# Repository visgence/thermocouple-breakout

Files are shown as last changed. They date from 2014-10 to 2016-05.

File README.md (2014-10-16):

The K-Type thermocouple conditioner is an easy way to use a K-Type thermocouple with an Arduino or other microcontrollers. At its heart is a AD595 thermocouple conditioner IC. The AD595 is laser trimmed for accuracy and performs automatic cold-junction compensation, which means you can just drop it into a project and get accurate results right away.

We created the K-Type Thermocouple Conditioner board while rebuilding our reflow toaster oven. The original controller used an AD595 and we were happy with its results. Since the toaster oven is a semi-permanent setup, we gave the board screw terminals and holes for robust mounting.

#### Specs
- [AD595A](http://www.analog.com/static/imported-files/data_sheets/AD594_595.pdf) laser trimmed for K-type thermocouple and 3 degree C basic accuracy
- 10mV / K output, easy to read with any ADC
- K-type input fits standard probes
- Alarm output and LED signals that probe is disconnected
- Screw terminals and mounting holes for easy long-term mounting

#### Use with an Arduino
We built our thermocouple conditioner specifically to use with Arduino and compatible boards. See the [example sketch](https://github.com/visgence/thermocouple-breakout/tree/master/example_code/thermocouple_conditioner_arduino) for a simple example.

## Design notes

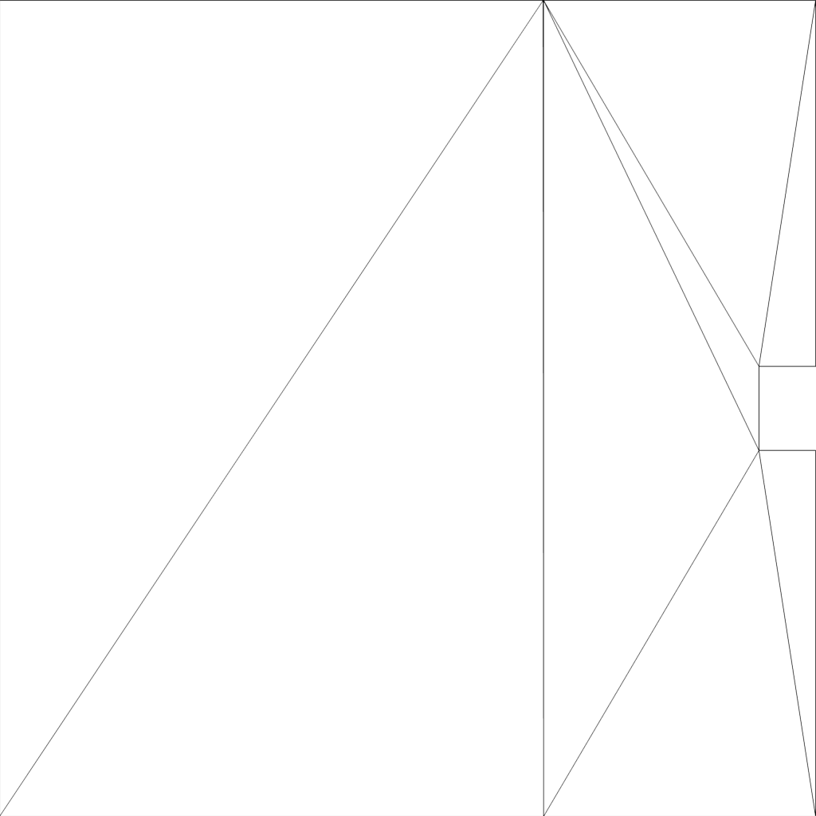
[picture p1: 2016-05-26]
hardware/BlenderModels/ThermoCoupleUVTop.png

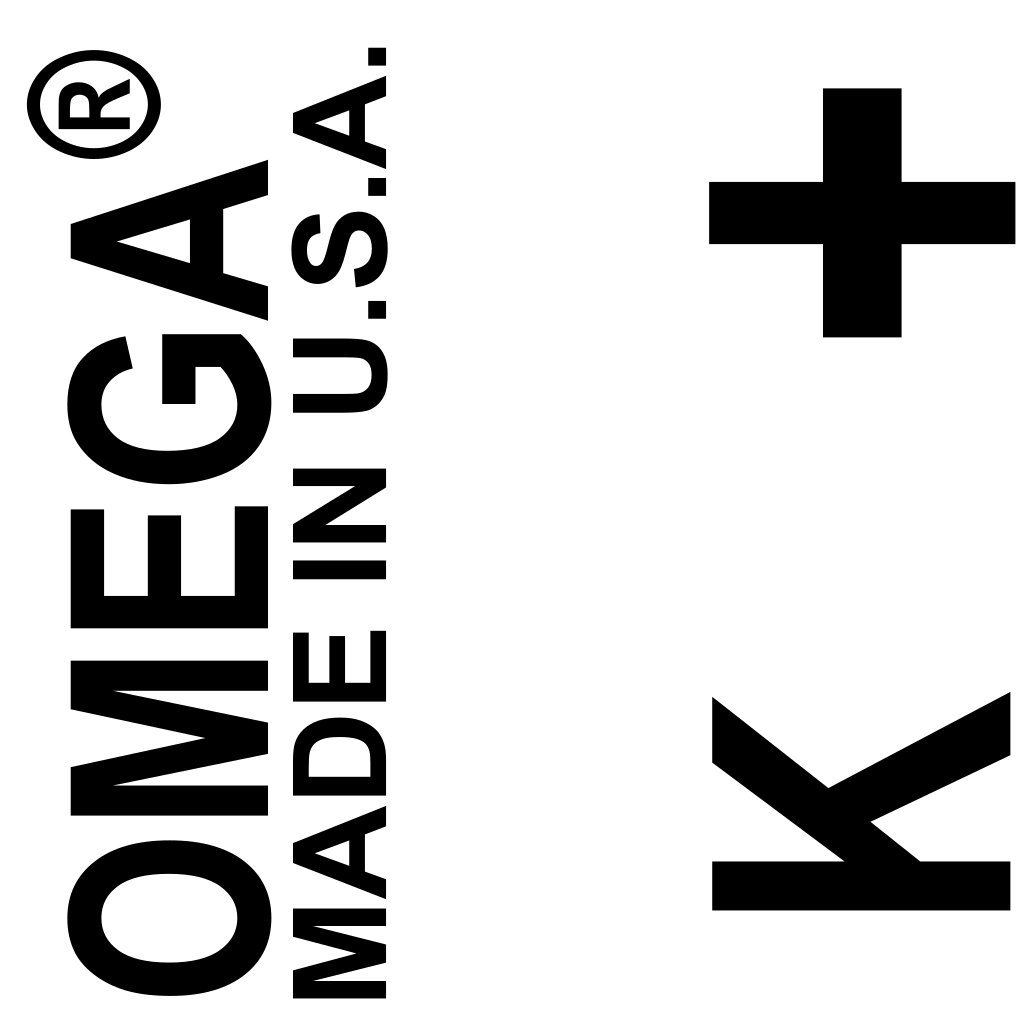
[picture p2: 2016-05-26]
hardware/BlenderModels/ThermoCoupleTopColor.png

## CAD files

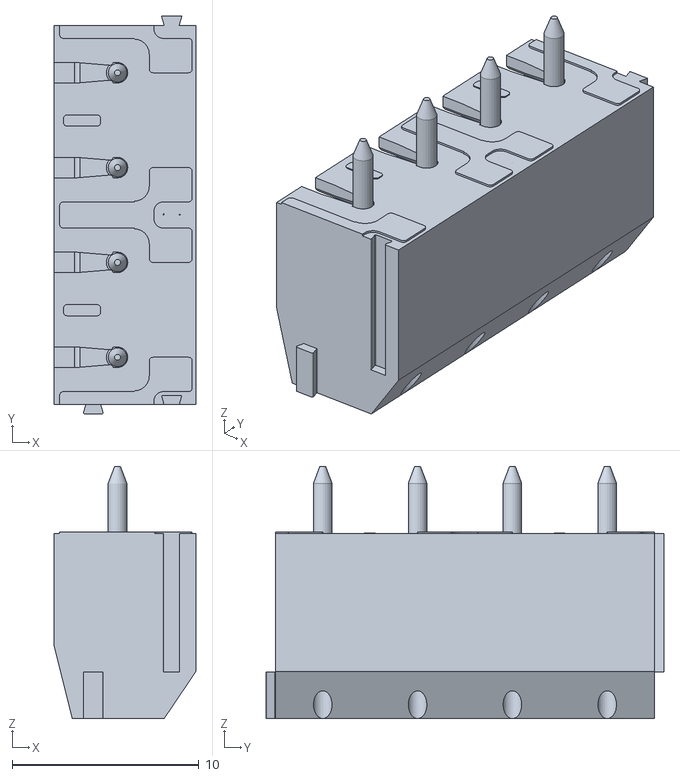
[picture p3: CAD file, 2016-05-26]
hardware/BlenderModels/OSTTCXX2162.obj
7.60 x 21.3 x 13.5

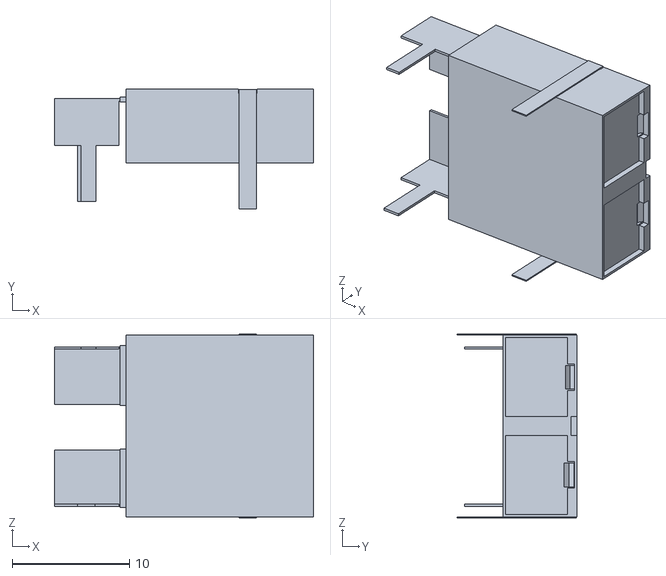
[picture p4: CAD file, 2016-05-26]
hardware/FusionModels/ThermoCouple.stl
22.1 x 10.3 x 15.7

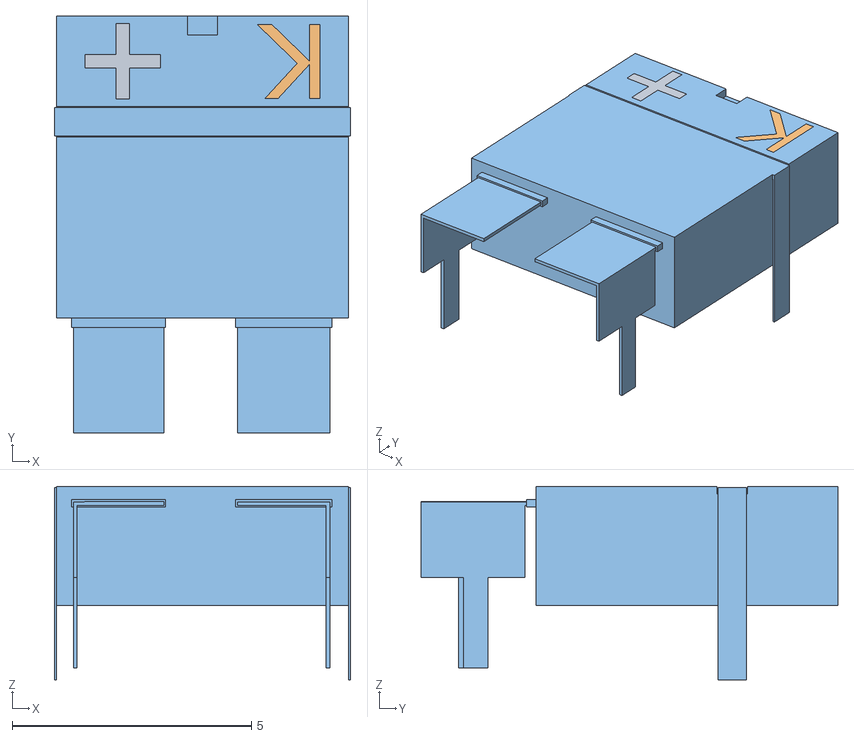
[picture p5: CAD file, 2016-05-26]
hardware/WingsTransfer/ThermoCouple.obj
6.19 x 8.71 x 4.07
K.001_Mesh.001
K_Mesh
ThermoCouple.001_ThermoCouple.003

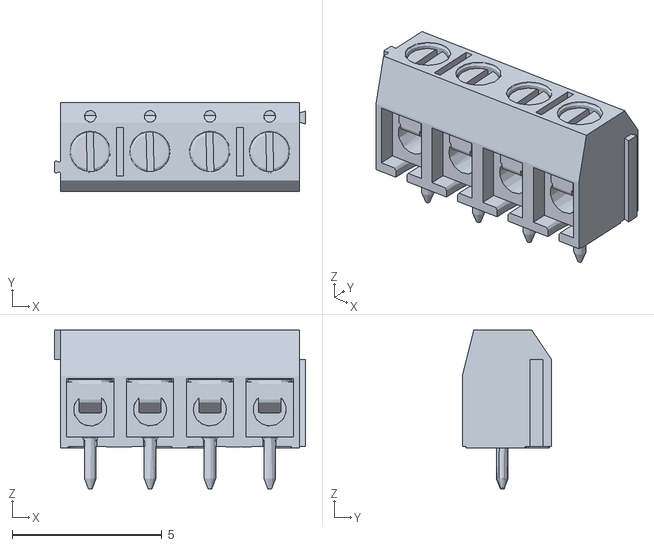
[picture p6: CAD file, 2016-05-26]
hardware/WingsTransfer/OSTTCXX2162.obj
8.39 x 2.99 x 5.32

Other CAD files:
hardware/BlenderModels/OSTTCXX2162.blend
hardware/BlenderModels/ThermoCouple.blend

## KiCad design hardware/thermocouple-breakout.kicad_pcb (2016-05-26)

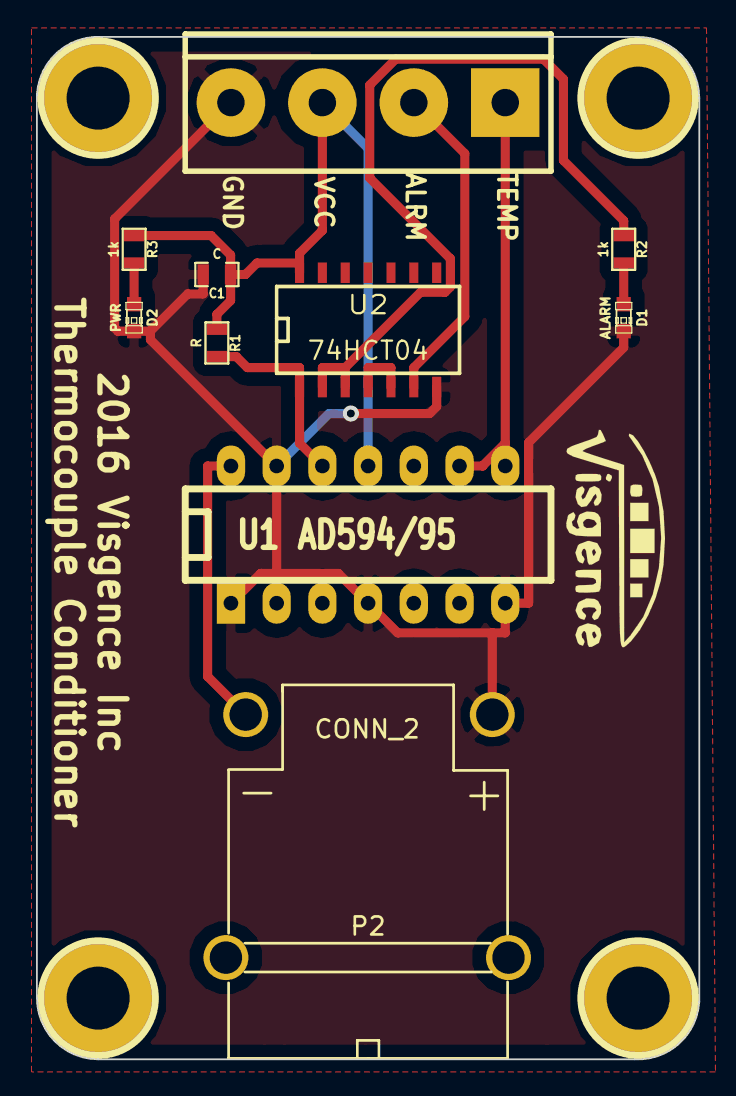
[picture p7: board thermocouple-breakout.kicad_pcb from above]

Board: 2 copper layers, 36.8 x 56.8 mm, 14 parts (0 on the bottom side), 10 nets.

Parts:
C1: C; SM0603_Capa_VIS
D1: ALARM; LED-0603
D2: PWR; LED-0603
P1: CONN_4; bornier4
P2: CONN_2; PCC-SMP
R1: R; SM0603_VIS
R2, R3: 1k; SM0603_VIS
U1: AD594/95; DIP-14__300_ELL
U2: 74HCT04; SO14N
h1, h2, h3, h4: pin; 1pin_C

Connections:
ALARM: P1.2, U2.6
GND: C1.2, D1.2, D2.2, P1.4, P2.1, U1.1, U1.4, U1.7, U1.13, U2.7
unnamed: D1.1, R2.2
unnamed: D2.1, R3.2
unnamed: P2.2, U1.14
unnamed: R1.2, U1.12, U2.1
unnamed: R2.1, U2.2, U2.3
unnamed: U2.4, U2.5
TEMP: P1.1, U1.8, U1.9
VCC: C1.1, P1.3, R1.1, R3.1, U1.11, U2.14

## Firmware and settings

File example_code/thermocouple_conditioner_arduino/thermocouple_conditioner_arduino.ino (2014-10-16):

/*
    Visgence, Inc. Thermocouple Conditioner Example
    
    This example code is in the public domain.
 */

int sensorPin = A0;
int alarmPin = 2;
int ledPin = 13;
int sensorValue = 0;
bool alarmState = 0;

float c, f;

float adc_to_celsius(int x){
    return ((float) x / 2.046);
}

float adc_to_farhenheight(int x){
    return (((float) x / 2.046 * 9.0 / 5.0) + 32.0);
}

void setup() {
    pinMode(ledPin, OUTPUT);  
    Serial.begin(9600);
}

void loop() {
    // turn the ledPin on
    digitalWrite(ledPin, HIGH);
    
    //is the probe plugged in?
    alarmState = digitalRead(alarmPin);

    if(alarmState){
        Serial.println("PROBE UNPLUGGED!");
    }

    else{
        // read the value from the sensor:
        sensorValue = analogRead(sensorPin);    

        c = adc_to_celsius(sensorValue);
        f = adc_to_farhenheight(sensorValue);

        Serial.print("ADC: ");
        Serial.print(sensorValue);
        Serial.print(" | ");
        Serial.print(c);
        Serial.print(" C ");
        Serial.print(" | ");
        Serial.print(f);
        Serial.print(" F ");
        Serial.println("");
    }

    // turn the ledPin off: 
    digitalWrite(ledPin, LOW);
    
    delay(1000);                  
}

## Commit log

2014-10-16 moved pcb files to their own folder
    [thermocouple-breakout.dsn, thermocouple-breakout.kicad_pcb, thermocouple-breakout.sch]
2014-10-16 adds an example arduino sketch
2016-05-21 Updated to kicad 4.0.2
    [thermocouple-breakout.kicad_pcb, thermocouple-breakout.sch]
2016-05-25 Began work on thermocouple layout. Began modeling custom pieces.
    [ThermoCouple.blend, ThermoCouple.stl, thermocouple-breakout.kicad_pcb]
2016-05-26 Finished thermocouple board in KiCad
    [OSTTCXX2162.blend, OSTTCXX2162.obj, ThermoCouple.blend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]
2016-05-26 Finishing up the termalcouple, exported JSON to 3dview repo.
    [OSTTCXX2162.blend, OSTTCXX2162.obj, ThermoCouple.blend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]
